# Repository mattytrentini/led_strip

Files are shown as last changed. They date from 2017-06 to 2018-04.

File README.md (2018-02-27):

# LED strip controller
Control an LED strip using an ESP8266, PWM, an N-Channel MOSFET, a rotary encoder and some Micropython

Uses SpotlightKid's [Rotary Encoder Library](https://github.com/SpotlightKid/micropython-stm-lib/tree/master/encoder). 
Just copy `encoder.py` from the above library, `ledstripcontroller.py`, and `main.py` to the ESP8266; tweak if your hardware is different!

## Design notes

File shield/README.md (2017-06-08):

# LED Strip Driver WeMos D1 Mini Shield

These are the [KiCad](http://kicad-pcb.org/) design files for a Shield for the WeMos D1 Mini that can be used to drive LED strips.

This is designed to be a compact, reusable, versatile, and web-connected design to allow for quick lighting solutions, as well as other simple, relatively high current generic driving applications.

The template for the WeMos D1 Mini shield came from jerome-labidurie's [Kicad tools for Wemos D1 mini](https://github.com/jerome-labidurie/d1_mini_kicad).

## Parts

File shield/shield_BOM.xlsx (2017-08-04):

Id | Designator | Quantity | Designation | Manufacturer | Manufacturer PN | Supplier | Supplier PN | Cost (AUD, ea) | Cost (total) | Package
1 | J1 | 1 | Screw_Terminal_1x04 | On Shore Technology Inc. | OSTVN04A150 | Digi-Key | ED10563-ND | 1.81 | 1.81 | TerminalBlock_Pheonix_MPT-2.54mm_4pol
2 | U1 | 1 | LM1117-3.3 | Texas Instruments | LM1117MPX-3.3/NOPB | Digi-Key | LM1117MPX-3.3/NOPBCT-ND | 1.36 | 1.36 | SOT-223
3 | P1, P2 | 2 | CONN_01X08 | Sullins Connector Solutions | PREC008SAAN-RC | Digi-Key | S1012EC-08-ND | 0.26 | 0.52 | D1_mini_Pin_Header
5 | C1 | 1 | 10uF | Taiyo Yuden | TMK212BBJ106KG-T | Digi-Key | 587-2985-1-ND | 0.25 | 0.25 | C_0805_HandSoldering
6 | C2, C4, C5 | 3 | 100nF | KEMET | C0805C104K5RACTU | Digi-Key | 399-1170-1-ND | 0.13 | 0.39 | C_0805_HandSoldering
7 | C3 | 1 | 22uF | Samsung Electro-Mechanics America, Inc. | CL21A226MQQNNNG | Digi-Key | 1276-6460-1-ND | 0.21 | 0.21 | C_0805_HandSoldering
8 | J2 | 1 | Screw_Terminal_1x02 | On Shore Technology Inc. | OSTVN02A150 | Digi-Key | ED10561-ND | 1.19 | 1.19 | TerminalBlock_Pheonix_MPT-2.54mm_2pol
9 | J4 | 1 | Screw_Terminal_1x06 | On Shore Technology Inc. | OSTVN06A150 | Digi-Key | ED10565-ND | 2.32 | 2.32 | TerminalBlock_Pheonix_MPT-2.54mm_6pol
10 | R1, R2, R3 | 3 | 220R | Yageo | RC0805FR-07220RL | Digi-Key | 311-220CRCT-ND | 0.13 | 0.39 | R_0805_HandSoldering
11 | R4, R5, R6 | 3 | 27k | Yageo | RC0805FR-0727KL | Digi-Key | 311-27.0KCRCT-ND | 0.13 | 0.39 | R_0805_HandSoldering
12 | Q3, Q2, Q1 | 3 | Q_NMOS_GSD | Diodes Incorporated | DMN3404L-7 | Digi-Key | DMN3404LDICT-ND | 0.59 | 1.77 | SOT-23_Handsoldering
13 | ROT1 | 1 | ROTARY-ENCODER | TT Electronics/BI | EN12-HS11AF25 | Digi-Key | 987-1194-ND | 1.4 | 1.40 | SF-ROTARY-ENCODER
14 | D1 | 1 | D | Diodes Incorporated | B540C-13-F | Digi-Key | B540C-FDICT-ND | 0.72 | 0.72 | D_SMB-SMC_Universal_Handsoldering
 |  |  |  |  |  |  |  | BOM cost (AUD): | 12.72

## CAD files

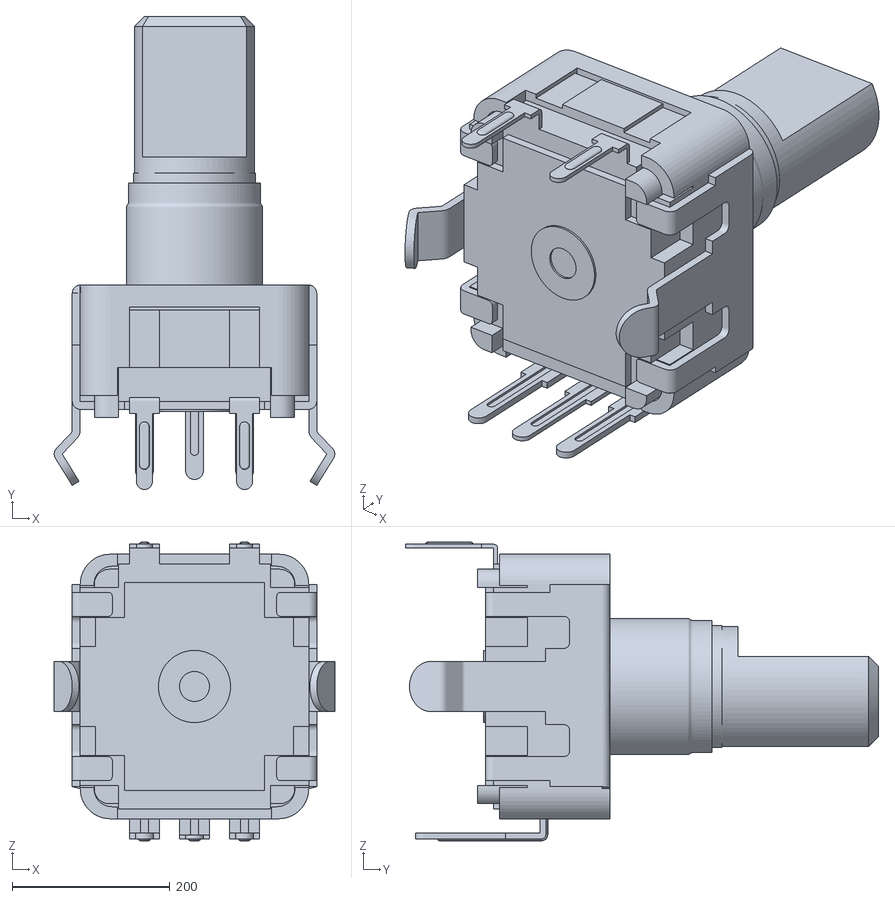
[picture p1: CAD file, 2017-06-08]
shield/3d/AB2_ROT_ENC_W_SW.stl
355.5 x 599.4 x 378.5

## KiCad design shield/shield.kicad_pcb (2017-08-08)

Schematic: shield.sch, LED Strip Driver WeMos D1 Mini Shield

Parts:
C1: 10uF; C_0805_HandSoldering
C2, C4, C5: 100nF; C_0805_HandSoldering
C3: 22uF; C_0805_HandSoldering
D1: D; D_SMB-SMC_Universal_Handsoldering
J1: Screw_Terminal_1x04; TerminalBlock_Pheonix_MPT-2.54mm_4pol
J2: Screw_Terminal_1x02; TerminalBlock_Pheonix_MPT-2.54mm_2pol
J4: Screw_Terminal_1x06; TerminalBlock_Pheonix_MPT-2.54mm_6pol
P1, P2: CONN_01X08; D1_mini_Pin_Header
Q1, Q2, Q3: Q_NMOS_GSD; SOT-23_Handsoldering
R1, R2, R3: 220R; R_0805_HandSoldering
R4, R5, R6: 27k; R_0805_HandSoldering
ROT1: ROTARY-ENCODER; SF-ROTARY-ENCODER
U1: LM1117-3.3; SOT-223

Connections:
+3V3: C3.1, J1.1, P2.1, U1.2 (VO), U1.4 (VO)
+12V: C1.1, D1.1 (K), J4.1, J4.3, J4.5, U1.3 (VI)
/+5V: P1.1
/A0: P2.7
/D0: P2.6
/D_OUT: J1.2, P2.2
/ENC_A: R4.1, ROT1.2 (A)
/ENC_B: R5.1, ROT1.4 (B)
/ENC_SWITCH: R6.2, ROT1.1 (SW1)
/LED_DRIVE_1: P2.3, R1.1
/LED_DRIVE_2: P2.4, R2.1
/LED_DRIVE_3: P2.5, R3.1
/MCU_A: C4.1, P1.6, R4.2
/MCU_B: C5.1, P1.5, R5.2
/MCU_SWITCH: C2.1, P1.3, R6.1
/PIR_IN: J1.3, P1.4
/RST: P2.8
/RX: P1.7
/TX: P1.8
GND: C1.2, C2.2, C3.2, C4.2, C5.2, J1.4, J2.2, P1.2, Q1.2 (S), Q2.2 (S), Q3.2 (S), ROT1.3 (C), ROT1.5 (SW2), U1.1 (GND/ADJ)
unnamed: D1.2 (A), J2.1
unnamed: J4.2, Q1.3 (D)
unnamed: J4.4, Q2.3 (D)
unnamed: J4.6, Q3.3 (D)
unnamed: Q1.1 (G), R1.2
unnamed: Q2.1 (G), R2.2
unnamed: Q3.1 (G), R3.2

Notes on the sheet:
GPIO2
GPIO0
GPIO4
GPIO5
GPIO15
GPIO13
GPIO12
GPIO14
GPIO16
WeMos D1 Mini connections
12V in
LED string outputs
General I/O
Rotary encoder with switch
3V3 regulator

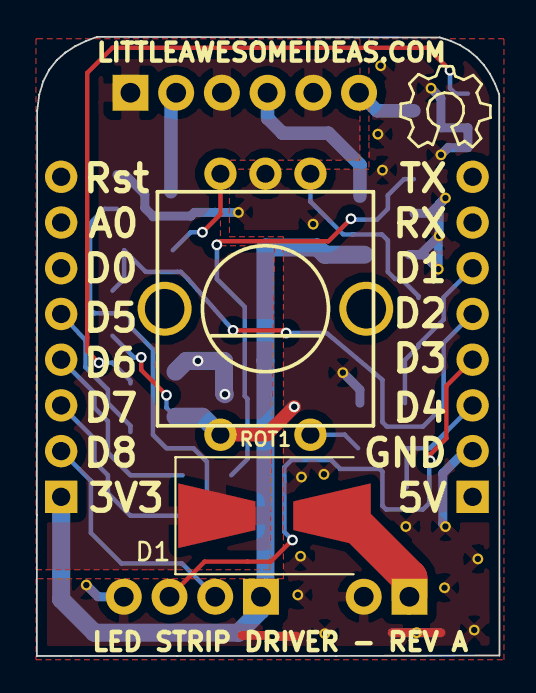
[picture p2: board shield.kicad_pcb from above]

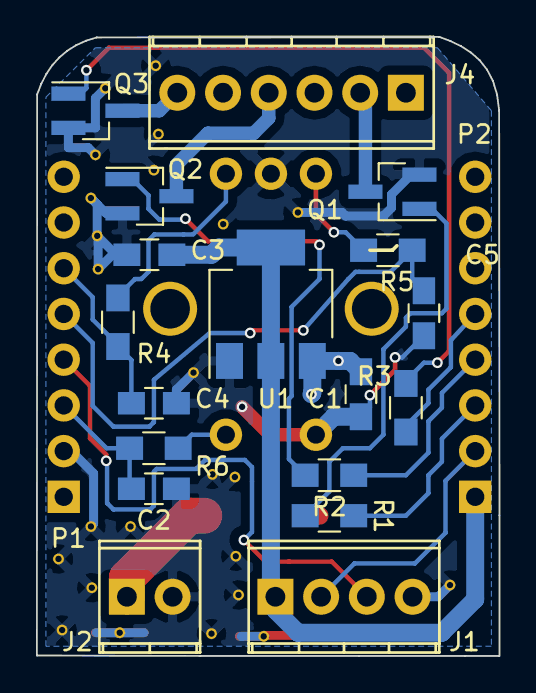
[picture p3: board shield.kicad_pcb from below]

Board: 2 copper layers, 25.7 x 34.4 mm, 22 parts (20 on the bottom side), 21 nets.

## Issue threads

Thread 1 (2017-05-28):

Debouncing needs to be handled

mattytrentini, 2017-05-28:
I tend to prefer hardware solutions (10nF cap across switch?). But could be done in software too.

Note that debouncing isn't really a problem when the brightness is high - the fade duration means that the debounce has stabilised by the time the fade is complete.

So, to test, reduce the brightness to the lowest setting and press the switch repeatedly. It's pretty easy to reproduce a repeat event (it will fade off then on - or vice versa - for one button click).

mattytrentini, 2017-05-29:
Debouncing has been worked around; the fades always take a full second now so debouncing is no longer an issue (it was before when the fade duration could be much shorter - see #2). Resolved in 340dec9333c38d0b624a81d8aff5eacc1dfdec87.

Closed 2017-05-29.

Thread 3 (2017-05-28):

Only listen to rotary encoder when LED strip is on

mattytrentini, 2017-05-28:
Currently the value of the encoder is recorded even when the LED strip is off.

This means that the LED strip can be turned off and the brightness changed before turning it on again. That's unexpected behaviour! Should ignore the encoder while the strip is off.

mattytrentini, 2017-05-29:
Fixed in commit ccde3265bb1acb2a00f95f77b10576fdf95351c9

Closed 2017-05-29.

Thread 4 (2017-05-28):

Fades should be able to be interrupted

mattytrentini, 2017-05-28:
The fade routine should be able to be interrupted. Specifically, if the strip is off and the switch is pushed a fade-in should begin...if the switch is pushed again before the fade is complete then the fade-in should be stopped and a fade-out should begin until the strip is off.

HowManyOliversAreThere, 2018-01-26:
Was this resolved in the move to async logic by @gidh ? (Implemented as at 0a40d1d190d6a429d6354e67f8cd80a0a55171fb)

gidh, 2018-01-26:
From memory, yes (it's been quite a while though!)

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

HowManyOliversAreThere, 2018-01-27:
Just tested and this is resolved - OK to close!

Closed 2018-01-27.

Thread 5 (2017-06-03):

led_strip_breadboard.fzz: Unable to find part

HowManyOliversAreThere, 2017-06-03:
Upon opening the led_strip_breadboard.fzz Fritzing file, an error pops up stating, "**Unable to find the following part:** 'Camdenboss_CTB0158-2_5_08mm_pitch_90deg_terminals' **at** '/home/USER/Documents/fritzing-VERSION/fritzing-parts/core/Camdenboss_CTB0158-2_5_08mm_pitch_90deg_terminals.fzp' ". Error seen on Fritzing 0.9.3b.

mattytrentini, 2017-06-03:
Hmm, interesting - as far as I can tell that's a [standard part](https://github.com/fritzing/fritzing-parts/blob/master/core/Camdenboss_CTB0158-2_5_08mm_pitch_90deg_terminals.fzp). I'm on 0.9.3b too! I'll investigate further tomorrow; if I can't work out what's going on I'll just replace that part with another...

mattytrentini, 2017-06-03:
By the way, here's an image of the breadboard:

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

HowManyOliversAreThere, 2017-06-05:
No terminal block for me - definitely seems to be referencing your local copy for some reason?

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

mattytrentini, 2017-06-06:
I just tried installing Fritzing on my work computer (Windows, whereas at home I'm on Ubuntu) and the board loaded fine, including the terminal block...hmm.

I'll try to find a moment to try to swap out to another component anyway.

HowManyOliversAreThere, 2017-06-06:
I'm on Windows 10, although it still seems strange that it's such a specific error - oh well, happy to write this off as something on my end!

Closed 2018-03-10.

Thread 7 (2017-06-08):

main.py: LED strip driving functions should be brought out into own class

HowManyOliversAreThere, 2017-06-08:
Currently the LED strip driving calls are all nestled within the main.py file. It would be good to extract these calls / functions, neaten them up, and place them in a class so that multiple LED strips can be driven at once. Fading and debouncing logic will have to be re-designed to a non-blocking implementation.

HowManyOliversAreThere, 2017-06-08:
Possible example of class usage:

```python
import led_strip
my_led_strip = led_strip(7) # LED strip driver connected to pin 7
my_led_strip.on() # turns theLED strip to full brightness
my_led_strip.pwm(70) # pulses the LED strip at 70% of the maximum PWM
print('PWM value: %i' % my_led_strip.getPwm()) # prints the current PWM value (0 for off, 100 for fully on)
my_led_strip.off() # turns the LED strip off
```

Could possibly also have `increment` and `decrement` functions that increase of decrease the pwm by a fixed amount, amount settable by a `setIncrements(incrementSize)` function

mattytrentini, 2017-06-08:
Agree with pulling the need to encapsulate the led strip functionality. And yes, some thought will need to be given to how to fade and debounce nicely, I'm leaning toward a design based around [asyncio](https://docs.python.org/3/library/asyncio.html). [This example](https://github.com/micropython/micropython/blob/master/examples/hwapi/soft_pwm_uasyncio.py) is close to what I'm thinking (though we'd use PWM support rather than do it manually).

As for the interface, you've made a good start though a couple of changes have popped out:
```python
from machine import PWM, Pin
import led_strip
my_led_strip = led_strip(machine.PWM(machine.Pin(7), freq=1000), max_duty=1023) # [1]
my_led_strip.on() # turns the LED strip to full brightness [2]
my_led_strip.brightness(70) # Set the strip to a percentage of maximum brightness [3]
print('Brightness: %i' % my_led_strip.brightness) # prints the current brightness value
my_led_strip.off() # turns the LED strip off [4]
```

1. I think we should just expect an object to be passed in that provides a 'duty' method rather than doing all the GPIO management internally. This makes it more composable and portable.
2. Just calls .duty(max_duty). Or .brightness(100).
3. Shouldn't really have 'pwm' in the interface. Probably needs to take a float
4. .duty(0)

But this is all off the top of my head, really need to experiment a little more...

HowManyOliversAreThere, 2018-01-26:
Class implementation has been resolved as at ef2ca578456f067787f2076fbe4f8cbc3fbb26fd

Closed 2018-03-10.

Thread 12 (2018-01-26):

Shield PCB: No silk screen annotations on connectors

HowManyOliversAreThere, 2018-01-26:
In the Rev A version of the shield PCB, there is no silk screen annotations on the connectors. This means that prior knowledge of the board is required for knowing how to connect the LED strips, and could very easily result in the strips being wired backwards (unlikely to be damaging for the strips, but could lead to some confusion).

This should be rectified for Rev B of the PCB.

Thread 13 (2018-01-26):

Shield PCB: No LEDs on board

HowManyOliversAreThere, 2018-01-26:
In the Rev A shield PCB, there are no LEDs built into the Design. This means testing functionality is harder than would be ideal.

Preferred setup would be to have an LED to show power on the 12V and 3V3 rails, as well as an LED across each of the LED strip terminals to show when they're powered. This should be implemented for Rev B of the PCB.

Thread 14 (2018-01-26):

Shield PCB: Debounce resistors too high

HowManyOliversAreThere, 2018-01-26:
The debounce resistors have too high a resistance (27k), which means that they cannot successfully overcome the pull-up resistors inside the ESP (10k). For example: Pressing the rotary encoder button results in a voltage of 2.5V, which does not trigger the button press interrupt.

HowManyOliversAreThere, 2018-01-26:
This affects R4, R5, and R6.

HowManyOliversAreThere, 2018-01-27:
Replaced resistors with 1k equivalents and now functional - suggest this value for Rev B design.

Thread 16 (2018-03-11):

Fade needs to be smoother

mattytrentini, 2018-03-11:
There are obvious steps in changing the brightness when fading, it should be smoother. If we put a simple fade routine in a (non-async) loop:

```py
from machine import Pin, PWM
from time import sleep_ms

led=PWM(Pin(22))
for i in range(1024):
	led.duty(i)
	sleep_ms(5)
```

It's _very_ smooth.

A few issues to consider:

- Need to time how long the async sleep was _actually_ asleep for
  - Just because we request x ms doesn't mean we will _exactly_ get it.
  - Initial measurements look like it's typically a few ms later (ie async.sleep_ms gives a _minimum_ sleep time)
  - Adjust the brightness step by the _actual time_ since the last step
- Use a _rate of change_ to adjust brightness
  - Something like 0-100% brightness in 1.5 sec
- May be best to change brightness to a percentage
- Brightness appear to be non-linear
  - Fade routine can work with a linear percentage but we can introduce a function to return a non-linear percentage
- The last step may need some care
  - For example if we get _very_ close to the goal brightness on the second-last step we may sleep for too long
- Need to time what the minimum sleep time of async.sleep_ms is
  - Initial measurements look like it can go down to 5ms though the documentation suggests 10's of ms is more realistic
  - Even a 20ms sleep should be able to look smooth? Need to test...
- Remember that print statements can affect the timing dramatically!
  - Maybe put them in another async loop that's serviced infrequently

mattytrentini, 2018-03-12:
Tried a non-async 20ms step (1.5s 0-100%) fade and it's _very_ smooth:

```py
from machine import Pin, PWM
from time import sleep_ms
def fadein():
    led=PWM(Pin(12))
    for i in range(0, 1024, 13): # 13 = 1024/(1500ms/20ms)
        led.duty(i)
        sleep_ms(20)
```

seanlano, 2018-07-29:
On the point:

> Brightness appear to be non-linear

I found that using an exponential function gave a better-looking response - in my case in the WiLED project I had a notion of "brightness steps", i.e. the dimmer would change between say five distinct levels only, rather than the full range PWM values. Then I have a mapping between those brightness levels and an actual PWM value. I suppose if you wanted to do 100 "brightness steps" then those would effectively be a percentage to PWM mapping.

The C++ code I have for it is:
```
float max_log10 = log10(led->getMaxPWM());
float steps_log10 = log10(NUM_DIM_STEPS-1);
float exponent = max_log10/steps_log10;
float result;
pwm_dim_levels[0] = 0;
for(int idx=1; idx<NUM_DIM_STEPS; idx++){
	result = pow(idx,exponent);
	pwm_dim_levels[idx] = int(result);
}
pwm_dim_levels[NUM_DIM_STEPS-1] = led->getMaxPWM();
```

The gist of it is though, suppose you want 8-bit values and 6 steps, you find the exponent with `exponent = log10(255)/log10(6) = 3.092638069` and then the actual value with `pwm = step ^ exponent`.

Then the values for each step are:
```
pwm_dim_levels[0] = 0
pwm_dim_levels[1] = 1
pwm_dim_levels[2] = 9
pwm_dim_levels[3] = 30
pwm_dim_levels[4] = 72
pwm_dim_levels[5] = 145
pwm_dim_levels[6] = 255
```

mattytrentini, 2018-07-29:
Thanks @seanlano!

I was had intended to insert a mapping shim method - pass a function a value from 0-100 and then have it return a non linear value from 0-100.  Something like what you've proposed ought to work well!

Looking forward to seeing your LED controller in the flesh... :)

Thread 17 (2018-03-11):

Add PIR to the system

mattytrentini, 2018-03-11:
A Passive InfraRed sensor could be used to detect when someone is nearby and turn on the LED strip automatically. Just need to hook this in to the broken-out GPIO and monitor it for changes.

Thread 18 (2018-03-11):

Need better control over LED strips on startup

mattytrentini, 2018-03-11:
Currently when the button is pressed the LED's come on temporarily at full brightness then back to completely off.

When the rotary encoder is pressed it _allows_ the LED's to be lit but starts them at 0 brightness. Once the encoder is turned it enforces a minimum brightness.

What should happen is that when the application starts the LED's should - perhaps - turn on and off quickly but with a very dim brightness. Then, if the rotary encoder is pressed, the LED's should be lit to the minimum brightness.

HowManyOliversAreThere, 2018-04-28:
Commit 98503565952ea704eea19dd15764a2eda591c734 sets initial LED brightness to 511 (out of 1023)- this is not the minimum brightness specified, but better than the previous behaviour (of being in an illegal state).

HowManyOliversAreThere, 2018-04-28:
Commit 031a866 strives to ensure that the LED drivers are disabled as soon as possible after startup, however there is still a period upon startup where the lights are on fairly strongly. I believe this can be attributed to the start-up time of Micropython combined with a lack of pull-down resistors on the LED_DRIVE_x nets. This should be resolved in the next revision of hardware - a new Issue (#20) has been created specifically for this implementation.

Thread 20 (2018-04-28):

Pull-downs on FET driver lines required

HowManyOliversAreThere, 2018-04-28:
Currently the LEDs are briefly on when the board is powered up before they turn off - see #18. Pull-down resistors need to be added to the LED_DRIVE_x nets in order to aid in resolving this issue.

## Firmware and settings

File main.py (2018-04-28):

from machine import Pin, PWM
from encoder import Encoder
from ledstripcontroller import LedStripController
from uasyncio import get_event_loop
from sys import platform

def main():
    dev_type = platform
    if dev_type == 'esp8266': # WEMOS D1 Mini (or similar)
        ENC_PINS = {'clk':4, 'dt':5, 'button':2}
        FADER_PINS = (12, 13, 14)
        FADER_FREQ = 1000
    elif dev_type == 'esp32': # TTGO
        ENC_PINS = {'clk':21, 'dt':22, 'button':16}
        FADER_PINS = (19, 23, 18)
        FADER_FREQ = 50000
    else: # Defaults
        ENC_PINS = {'clk':None, 'dt':None, 'button':None}
        FADER_PINS = (None, None, None)
        FADER_FREQ = None
    
    enc = Encoder(pin_clk=ENC_PINS['clk'], pin_dt=ENC_PINS['dt'], pin_mode=Pin.PULL_UP,
                  min_val=40, max_val=1020, clicks=1, accel=5)
    enc._value = 0

    fader_pins = [PWM(Pin(pin_num), freq=FADER_FREQ, duty=0) for pin_num in FADER_PINS]
    button = Pin(ENC_PINS['button'], Pin.IN, Pin.PULL_UP)
    controller = LedStripController(enc, button_pin=button, fader_pins=fader_pins)
    button.irq(trigger=Pin.IRQ_FALLING, handler=lambda _: controller.toggle_led_state())

    loop = get_event_loop()
    loop.create_task(controller.switch_loop(controller.enc))
    loop.create_task(controller.encoder_loop(controller.enc))
    loop.create_task(controller.fader_loop())
    loop.run_forever()
    controller.enc.close()

if __name__ == '__main__':
    main()

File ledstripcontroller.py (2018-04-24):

import uasyncio as asyncio

class LedStripController:

    def __init__(self, enc, button_pin, fader_pins):
        ''' enc should be an instance of Encoder.
            button_pin is expected to be an instance of machine.Pin.
            fader_pins is expected to be an iterable of machine.PWM's. 
        '''
        self.enc = enc
        self.is_on = False
        self.enc_cur_val = 511
        self.fader_target_val = 0
        self.button_pin = button_pin
        self.fader_pins = fader_pins
        self.button_pressed = False
        for fader in self.fader_pins:
            fader.duty(0)

    def toggle_led_state(self):
        self.button_pressed = True
        print('Button pressed!')

    async def switch_loop(self, enc):

        self.button_pressed = False

        while True:
            if self.button_pressed:
                # TODO should removedebouncing; should be handled outside of this class.
                # Shouldn't care that it's a button that triggers the change...
                asyncio.sleep_ms(100) # Debounce duration
                # Only alter state if button still pressed (not a transient event)
                if not self.button_pin.value():
                    if self.is_on:
                        # Turning off, fading out
                        print('Turning off at {}'.format(self.enc_cur_val))
                        self.fader_target_val = 0
                    else:
                        # Turning on, fading in
                        print('Turning on at {}'.format(self.enc_cur_val))
                        self.fader_target_val = enc._value = self.enc_cur_val
                    self.button_pressed = False
                    self.is_on = not self.is_on
            await asyncio.sleep_ms(100)

    async def encoder_loop(self, enc):

        oldval = 0

        while True:
            if self.is_on:
                self.enc_cur_val = enc.value
                enc.cur_accel = max(0, enc.cur_accel - enc.accel)
                if oldval != self.enc_cur_val:
                    print('Old enc. val: %i, new enc. val: %i' % (oldval, self.enc_cur_val))
                    self.fader_target_val = oldval = self.enc_cur_val
            await asyncio.sleep_ms(50)

    async def fader_loop(self):

        FADER_MAX_STEP = 5
        FADER_DELAY_MS = 5

        fader_cur_val = 0

        while True:

            if self.fader_target_val > fader_cur_val:
                step = min(FADER_MAX_STEP, self.fader_target_val - fader_cur_val)
            elif self.fader_target_val < fader_cur_val:
                step = -min(FADER_MAX_STEP, fader_cur_val - self.fader_target_val)
            else:
                step = 0

            fader_cur_val += step
            if abs(step) > 0:
                for fader in self.fader_pins:
                    fader.duty(fader_cur_val)

            await asyncio.sleep_ms(FADER_DELAY_MS)

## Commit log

2017-05-28 Updated README.md to link to the SpotlightKid's Rotary Encoder library and tidied up the Fritzing breadboard view.
    [led_strip_breadboard.fzz]
2017-05-29 Very hacky workaround to ignore the rotary encoder except when LED's are fully on (ie not off or fading).
    Can definitely reduce the number of variables...
    [main.py]
2017-06-05 Initial commit of KiCad design files for a WeMos D1 Mini Shield that implements the LED Strip driving concept in a more compact, reliable, and repeatable fashion.
    Changes:
    * shield/*
    * Added KiCad design files
    * Added README.md giving brief description of intent and tools used
    * .gitignore
    * Added KiCad targeted ignores
    [shield.kicad_pcb, shield.sch]
2017-06-06 Modified the shield design to utilise a 3V3 LDO instead of 5V regulator module. Powering the Wemos D1 Mini through it's 3V3 pin instead of 5V (effectively bypassing the onboard regulator).
    [shield.sch]
2017-06-06 Schematic changes as per merge request discussion, and beginning PCB layout
    * Schematic
    * Changed rotary encoder schematic part
    * Added debounce circuitry to all rotary encoder signal lines
    * Changed rotary encoder pinout to match existing circuitry
    * Changed MOSFETs to GSD style
    * Added footprints for all components (ensuring hand solderability of all components)
    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
    [AB2_ROT_ENC_W_SW.stl, shield.kicad_pcb, shield.sch]
2017-06-13 Updated PCB to have rotary encoder on top side of PCB and terminal blocks on bottom of PCB. PCB outline slightly adjusted to allow for large components (now overhangs the incuts on the Wemos board fo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
    [shield.kicad_pcb]
2017-06-16 Rotated J1 to face bottom edge, and brought J1 and J2 closer to centre of PCB
    [shield.kicad_pcb]
2017-08-03 Routed PCB, and added a filled-out BOM (Digi-Key source)
    [shield.kicad_pcb, shield_BOM.xlsx]
2017-08-07 Updated PCB to 2 layers - WIP
    [shield.kicad_pcb]
2017-08-07 Finished updating PCB to 2 layers
    [shield.kicad_pcb]
2017-09-27 Tidy up Disable changing encoder value when in switched off state Wrap in a class
2018-01-27 Multiple changes in line with making the shield PCB work
    * LedStripController class brought out into it's own file
    * main.py simplified
    * main_shield.py created for initialisation of shield PCB
    * In the LedStripController class:
    ** Extra check added for more robust debouncing
    ** Added prints for debugging
    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
2018-02-28 Removed references to machine.Pin and machine.PWM from inside ledstripcontroller. Changed to use the millisec version of async.sleep.
2018-03-06 Added the most basic of Makefiles to deploy the files to an ESP device over serial using mpfshell.
2018-04-24 Multiple changes
    * Set default brightness to half-on
    * Defaults to off
    * Set pins to work with the ESP32 TTGO board
    * Moved event loop to main
2018-04-28 Generalising initialisation to depend on the type of board detected
    Now allows for either the Wemos D1 Mini series or the TTGO boards to be used
2018-04-28 Ensuring LED drivers default to not being driven - refs #18
